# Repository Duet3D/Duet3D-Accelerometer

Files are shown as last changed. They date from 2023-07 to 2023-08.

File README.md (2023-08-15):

# Duet3D-Accelerometer
A standalone accelerometer board using the LIS3DH MEMS digital motion sensor. It is designed to plug into the SPI daughterboard header on Duet 2 and 3 mainboards.

Duet_3_Accelerometer_02_s_9f60be45_thumbnail_256 1

Product Page:
[https://www.duet3d.com/duet3d-accelerometer](https://www.duet3d.com/duet3d-accelerometer)

Documentation is here:

[Duet 3 Accelerometer Documentation](https://docs.duet3d.com/en/Duet3D_hardware/Accessories/Duet3D_Accelerometer)

licensed under the "CERN-OHL-S v2" or any later version plus the "Additional Duet3D Licence Terms",
see https://github.com/Duet3D/Duet3-Mainboard-6HC/blob/master/LICENSE

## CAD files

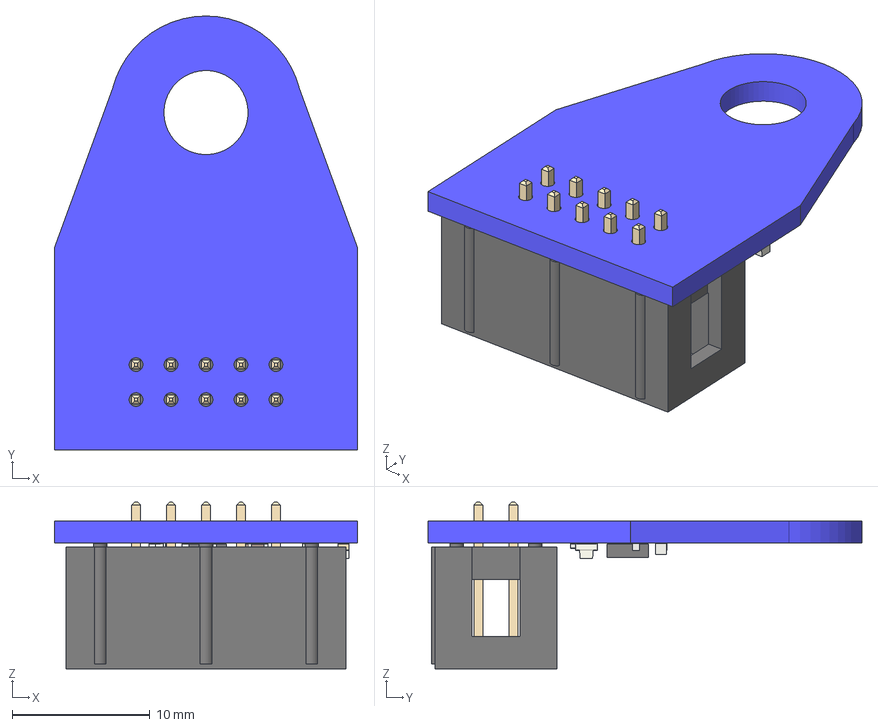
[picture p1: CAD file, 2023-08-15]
Duet3D Accelerometer v0.2/Duet3_accelerometer.step
22.0 x 31.5 x 12.1 mm
Duet3_accelerometer PCB

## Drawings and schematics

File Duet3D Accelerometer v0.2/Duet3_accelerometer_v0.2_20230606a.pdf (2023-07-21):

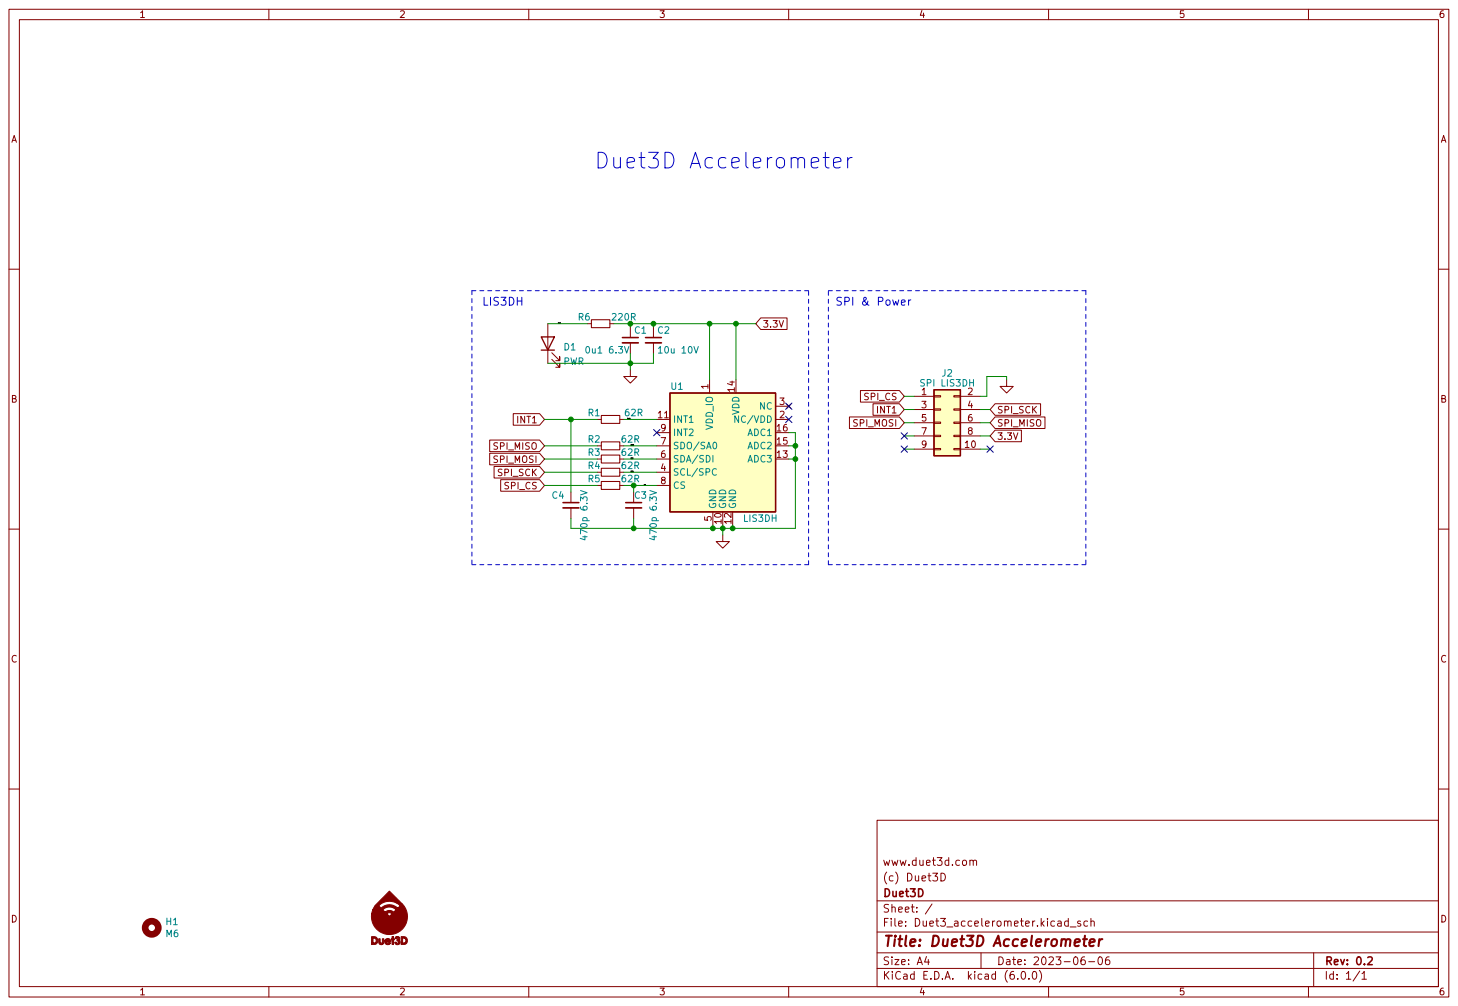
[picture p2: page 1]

5 SDA/SDI 6 SDO/SA0 7 CS 8

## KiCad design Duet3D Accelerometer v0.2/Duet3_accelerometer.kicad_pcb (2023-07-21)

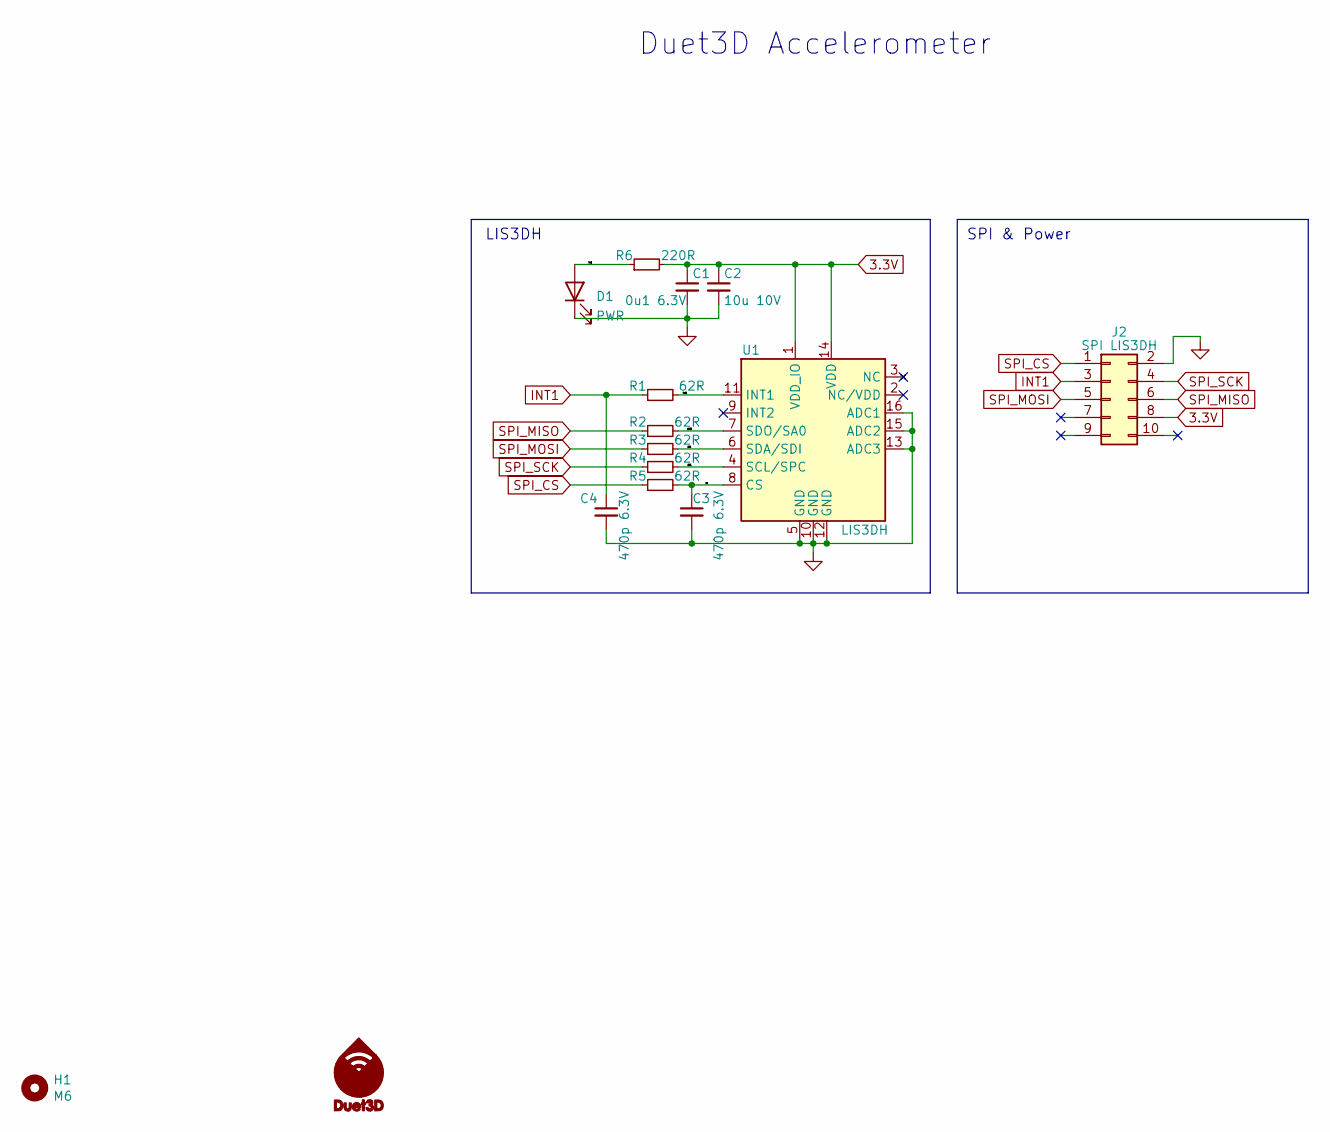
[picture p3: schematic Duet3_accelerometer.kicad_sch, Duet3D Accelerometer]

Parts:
C1: 0u1 6.3V; C_0402_1005Metric_Wbry; Part Number 1uF 6.3V X7R 0402
C2: 10u 10V; C_0603_1608Metric_Wbry; Part Number 10u 10V 10% X7R
C3, C4: 470p 6.3V; C_0402_1005Metric_Wbry; Part Number 6.3V 10% X7R 0401
D1: PWR; LED_0603_1608Metric; Part Number 150060VS75000 or equivalent Green
H1: M6; MountingHole_6mm
J2: SPI LIS3DH; IDC-Header_2x05_P2.54mm_Vertical
M1: Logo_Duet3d_New; LOGO_NEW_Duet3D_vertical_6mm_no_mask
R1, R2, R3, R4, R5: 62R; R_0402_1005Metric_Wbry; Part Number 62R 1% 0402
R6: 220R; R_0402_1005Metric_Wbry; Part Number 62R 1% 0402
U1: LIS3DH; LGA-16_3x3mm_P0.5mm_LISD3H; Part Number LIS3DHTR

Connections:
3.3V: C1.1, C2.1, J2.8, R6.2, U1.1 (VDD_IO), U1.14 (VDD)
/SCL: R4.2, U1.4 (SCL/SPC)
/SDI: R3.2, U1.6 (SDA/SDI)
/SDO: R2.2, U1.7 (SDO/SA0)
/cs: C3.1, R5.2, U1.8 (CS)
/int1: R1.2, U1.11 (INT1)
/led: D1.2 (A), R6.1
GND: C1.2, C2.2, C3.2, C4.2, D1.1 (K), J2.2, U1.5 (GND), U1.10 (GND), U1.12 (GND), U1.13 (ADC3), U1.15 (ADC2), U1.16 (ADC1)
INT1: C4.1, J2.3, R1.1
SPI_CS: J2.1, R5.1
SPI_MISO: J2.6, R2.1
SPI_MOSI: J2.5, R3.1
SPI_SCK: J2.4, R4.1

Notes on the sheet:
Duet3D Accelerometer
LIS3DH
SPI & Power

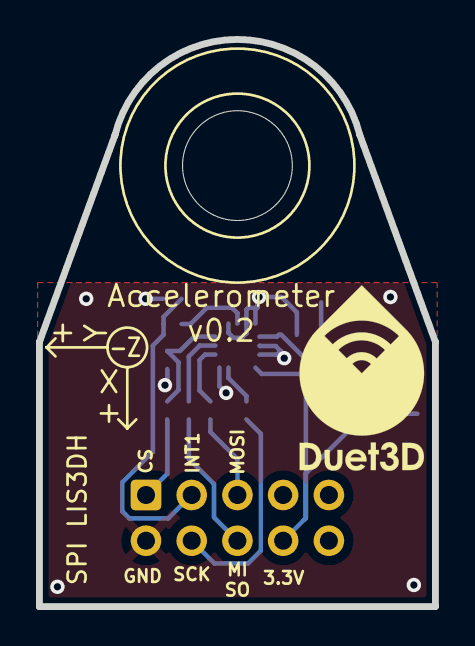
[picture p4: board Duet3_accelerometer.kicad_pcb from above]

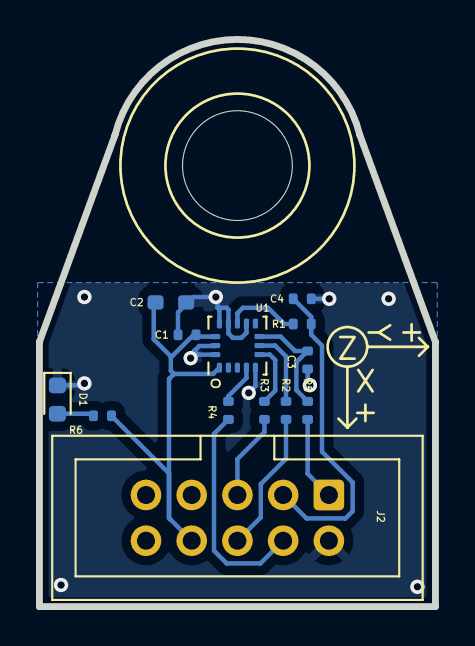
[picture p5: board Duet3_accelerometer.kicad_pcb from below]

Board: 2 copper layers, 22.0 x 31.5 mm, 15 parts (13 on the bottom side), 13 nets.

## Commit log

2023-07-21 Added v0.2 source
    [Duet3_accelerometer.kicad_pcb, Duet3_accelerometer.kicad_sch]
2023-08-15 Added STEP file
    [Duet3_accelerometer.step]
